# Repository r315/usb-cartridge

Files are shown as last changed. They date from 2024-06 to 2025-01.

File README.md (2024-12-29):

# GameBoy USB Cartridge

## Project Overview

Welcome to the GameBoy USB Cartridge project! This project aims to replicate a classic GameBoy cartridge and enhance it by adding a USB interface. This modification allows users to change the ROM content of the cartridge via a USB connection, making it a versatile and modern tool for GameBoy enthusiasts, developers, and collectors.

## Features

- **Classic GameBoy Cartridge Design**: Faithfully replicates the original cartridge's form factor and functionality.
- **USB Interface**: Enables easy ROM updates and data transfer through a USB connection.
- **Custom ROM Support**: Upload and play custom ROMs without the need for additional hardware.
- **Open Source**: Fully open-source hardware and software design, encouraging community contributions and modifications.

## Table of Contents

1. [Getting Started](#getting-started)
1. [Hardware Requirements](#hardware-requirements)
1. [Software Requirements](#software-requirements)
1. [Installation](#installation)
1. [Usage](#usage)
1. [Final notes](#final-notes)
1. [License](#license)

## Getting Started

GameBoy USB Cartridge is a diy project, so a custom pcb must be ordered and assembled.
I consider this project as dificult, since it requires the soldering of very fine pitch components
and requires good knowledge electronics and microcontroller wolkings in case of debug.

### Prerequisites

Ensure you have the following components and tools:

- GameBoy or GameBoy Color console
- Access to 3D printer for printing cartridge shell.
- Soldering tools and supplies
- Required hardware for Afterburrner gal programmer
- Jtag harware tool with SWD support

## Hardware Requirements

- **USB Cartridge pcb**: A bare pcb from your favorite pcb manufacturer (see hardware folder for schematic and gerber files)
- **Components**: Parts to populate pcb (see bom file on hardware folder)

## Software Requirements

- **Firmware Development**: Arm GNU Toolchain from arm Develop.
- **Afterburner pal programming**:  https://github.com/ole00/afterburner
- **Jtag software**: Can be Jlink or Openocd

## Installation

### Hardware Assembly

- Follow available schematic and assembly files.
- **Apply correction**: PCB has an error, in which the address line A0 is not connected to the correct pin of nor flash memory.
The workaround is connect a thin wire between pin 45 (Q15/A-1) to micro controller pin 36 (PF7).
- **Print 3D Case**: check cad files under hardware/case folder

<a href="/hardware/correction.jpg" target="_blank">
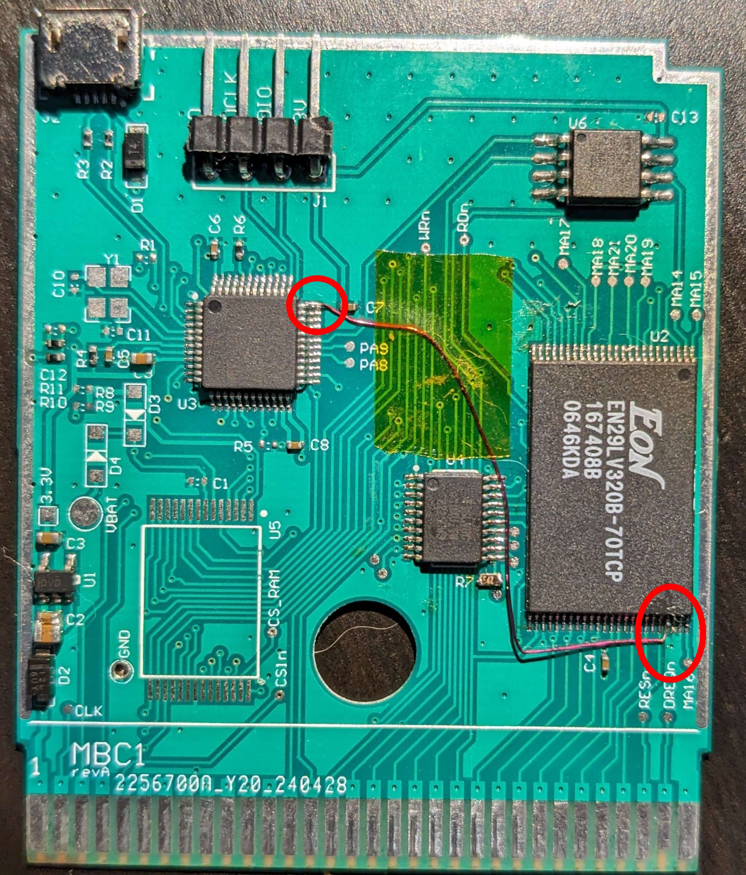
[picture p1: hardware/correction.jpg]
GameBoy USB Cartridge
    
</a>

### Firmware Upload

#### Programming pal

A JED file is provided for programming the pal, for his step I have used a modified version of Afterburner for Arduino with custom
hardware on a breadboard, but recommend using an Arduino with Afterburner.

The pal source file is also avaialble *mbc1.pld* and can be compiled with Wincupl, it is possible to compile a version that supports ram
but is limits the rom size and it has not been tested.

#### Programming microcontroller

To build microcontroller firmare, install Toolchain (I have used gcc version 10.3.1) and run *make* command.
If build is successful, *usb-cartridge.elf* will be available on *build* folder, use your jtag tool to program microcontroller.

## Usage

If all goes well with hardware and firmware, connecting USB Cartridge to a pc a serial device should be detected.
Also an unformated usb drive should be detected, format it as FAT.

Copy a rom file to that drive, the maximum rom size is 256kB, open a serial terminal and run commands:

1. `mount 1` this command mounts volume inside microcontroller.
1. `list`     list available files.
1. `rom program <romname>` programs given rom file into flash.

There are several other commands, typing *help* list all avaialble commands, typing some commands without parameters prints help of that command.
Code can be also checked for more command information.

Filally insert the cartrige and enjoy!

## Final notes

As mentioned this is a dificult project that requires good knowledge in electronics, since there is a lot of information that is 
omitted or not documented. One example is the flash memory support, I have used devices that were available to me and written drivers 
for them, it is very unlikely that the same parts will be available to other persons.
Firmware was written having that assumption in mind and flash driver is implemented in a way that should be easy to add new flash devices
or port it to other microcontroller.

If a new HW revision is drawn that fixes the error on address lines, firmware should also be udated in order to remove implemented workaround.

On mechanical side the 3D model for the case does not have an opening for USB connector, FreeCad project is available to be modified or a simple x-acto knife can be used to cut the opening.

## License

This project is licensed under the MIT License - see the [LICENSE](LICENSE) file for details.

---

Thank you for your interest in the GameBoy USB Cartridge project! We hope you enjoy building and using this modern take on a classic gaming accessory. If you have any questions or need assistance, please feel free to open an issue in the repository.

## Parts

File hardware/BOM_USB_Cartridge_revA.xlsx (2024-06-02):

Quantity | Designator | Comment | Description | Footprint | Value
1 | U2 | EN29LV320B-70TCP | FLASH - NOR Memory IC 64Mb (8M x 8) Parallel 70ns 48-TSOP | TSOP-48 | 64Mbit
1 | U3 | AT31F415CBT7 | Microcontroller - 32bit cortex-m4 | LQFP48_M
1 | U4 | ATF16V8C | EEPLD | TSSOP-20
1 | U6 | MX25L1635 | serial flash memory | SOP 8L (200mil) | 16Mbit
2 | R2, R3 | 0R | Resistor | R0402_HA | 0R
2 | D1, D2 | Diode | Generic Diode | SOD123 | 1N5711
3 | C2, C3, C9 | 1uF | Ceramic Capacitor, Ceramic Capacitor, Polarized Capacitor (Surface Mount) | C0603_HA | 1uF
6 | R1, R4, R5, R6, R10, R11 | 10k | Resistor | R0402_HA | 10k
1 | C4 | 10uF | Ceramic Capacitor | C0402_HA | 10uF
5 | C5, C6, C7, C8, C13 | 100nF | Ceramic Capacitor, Capacitor, Capacitor, Capacitor, Ceramic Capacitor | C0402_HA | 100nF
1 | J2 | CMU065803001 | MICRO USB 5P FEMALE DIP B -TYPE | CMU065803001 | CMU065803001
1 | U1 | RT9193-33 or Compatible | 300mA, Ultra-Low Noise, Ultra-Fast CMOS LDO Regulator | SOT23-5 | RT9193

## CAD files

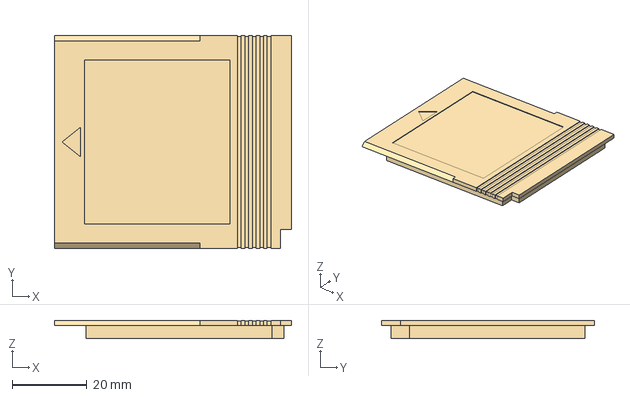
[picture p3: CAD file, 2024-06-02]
hardware/case/Cartridge-Lid.step
63.5 x 57.0 x 4.90 mm

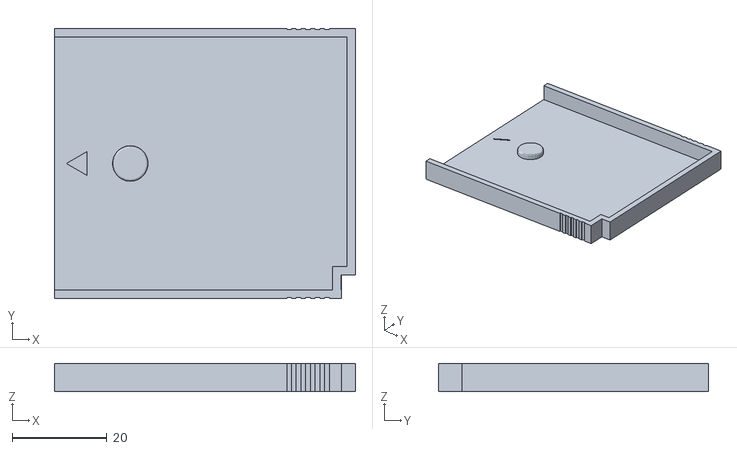
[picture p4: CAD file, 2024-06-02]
hardware/case/Cartridge-Base.stl
63.5 x 57.0 x 6.00

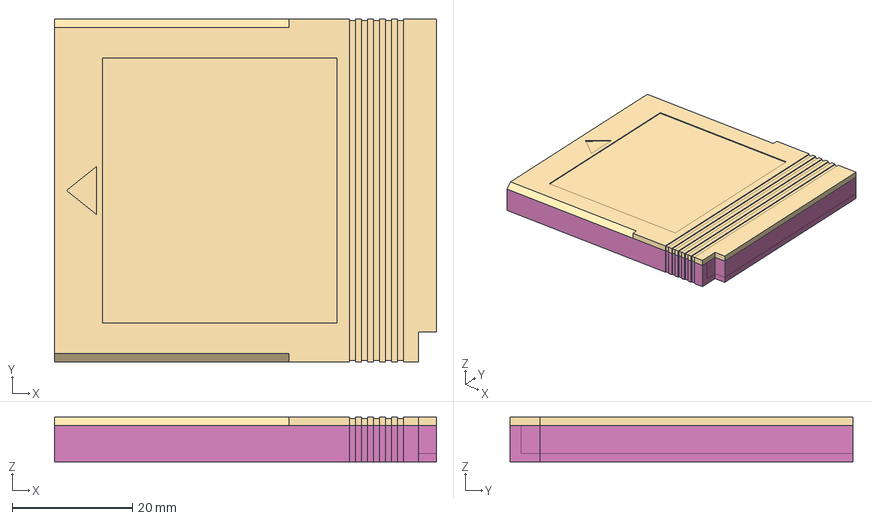
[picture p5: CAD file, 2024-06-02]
hardware/case/Cartridge.FCStd
63.5 x 57.0 x 7.40 mm
Base
Lid

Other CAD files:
hardware/case/Cartridge-Lid.stl

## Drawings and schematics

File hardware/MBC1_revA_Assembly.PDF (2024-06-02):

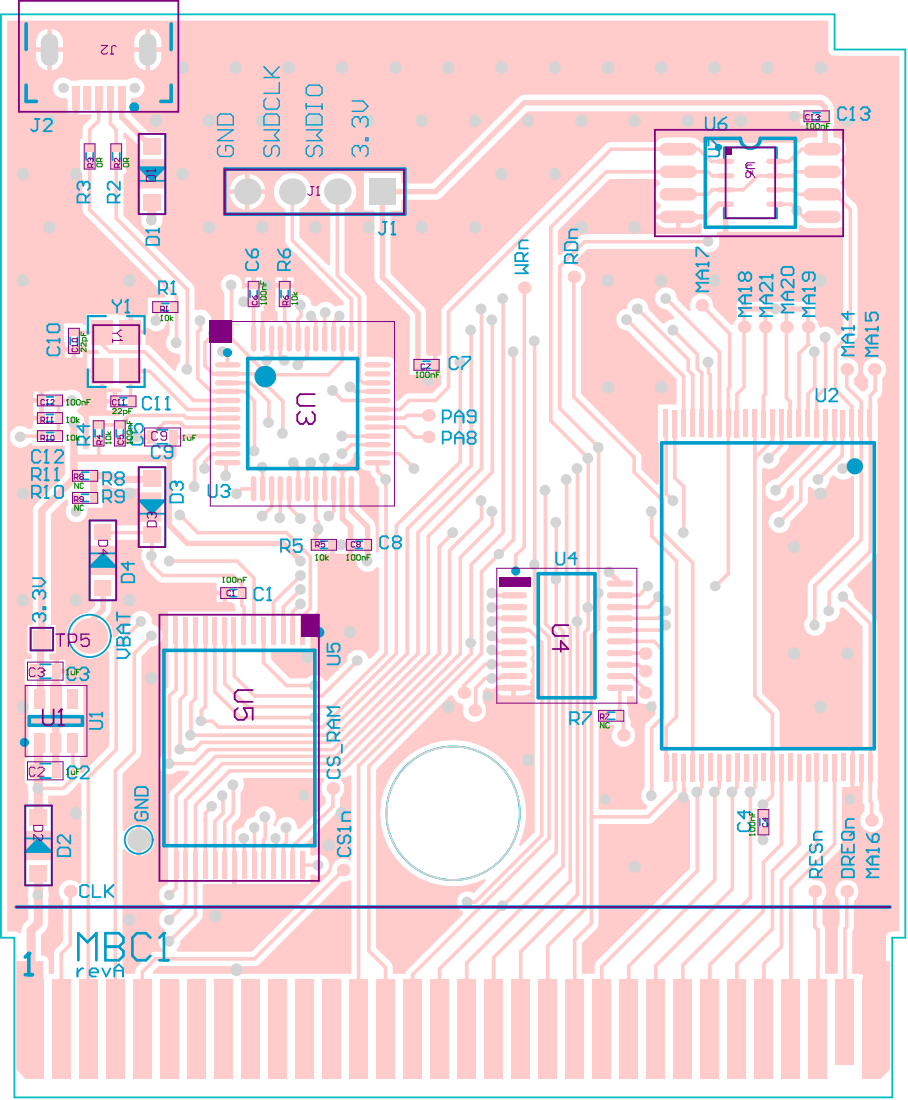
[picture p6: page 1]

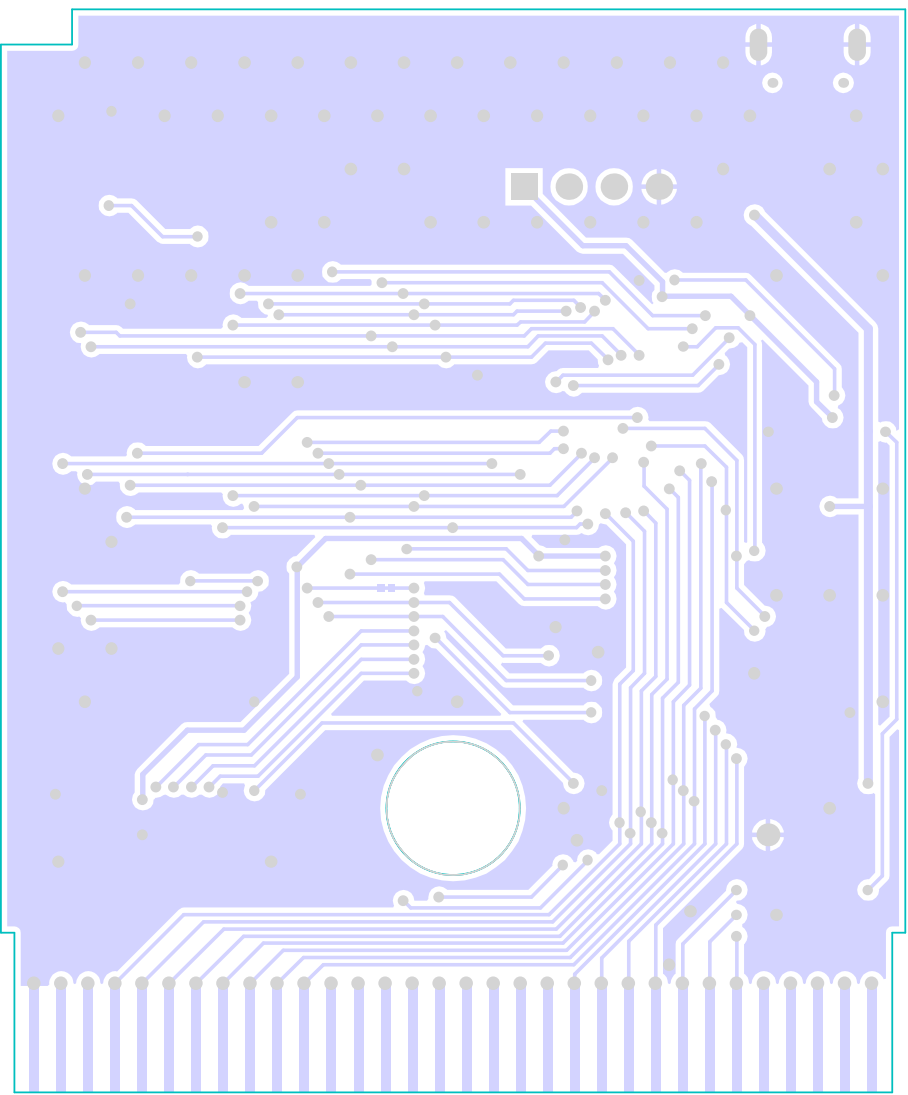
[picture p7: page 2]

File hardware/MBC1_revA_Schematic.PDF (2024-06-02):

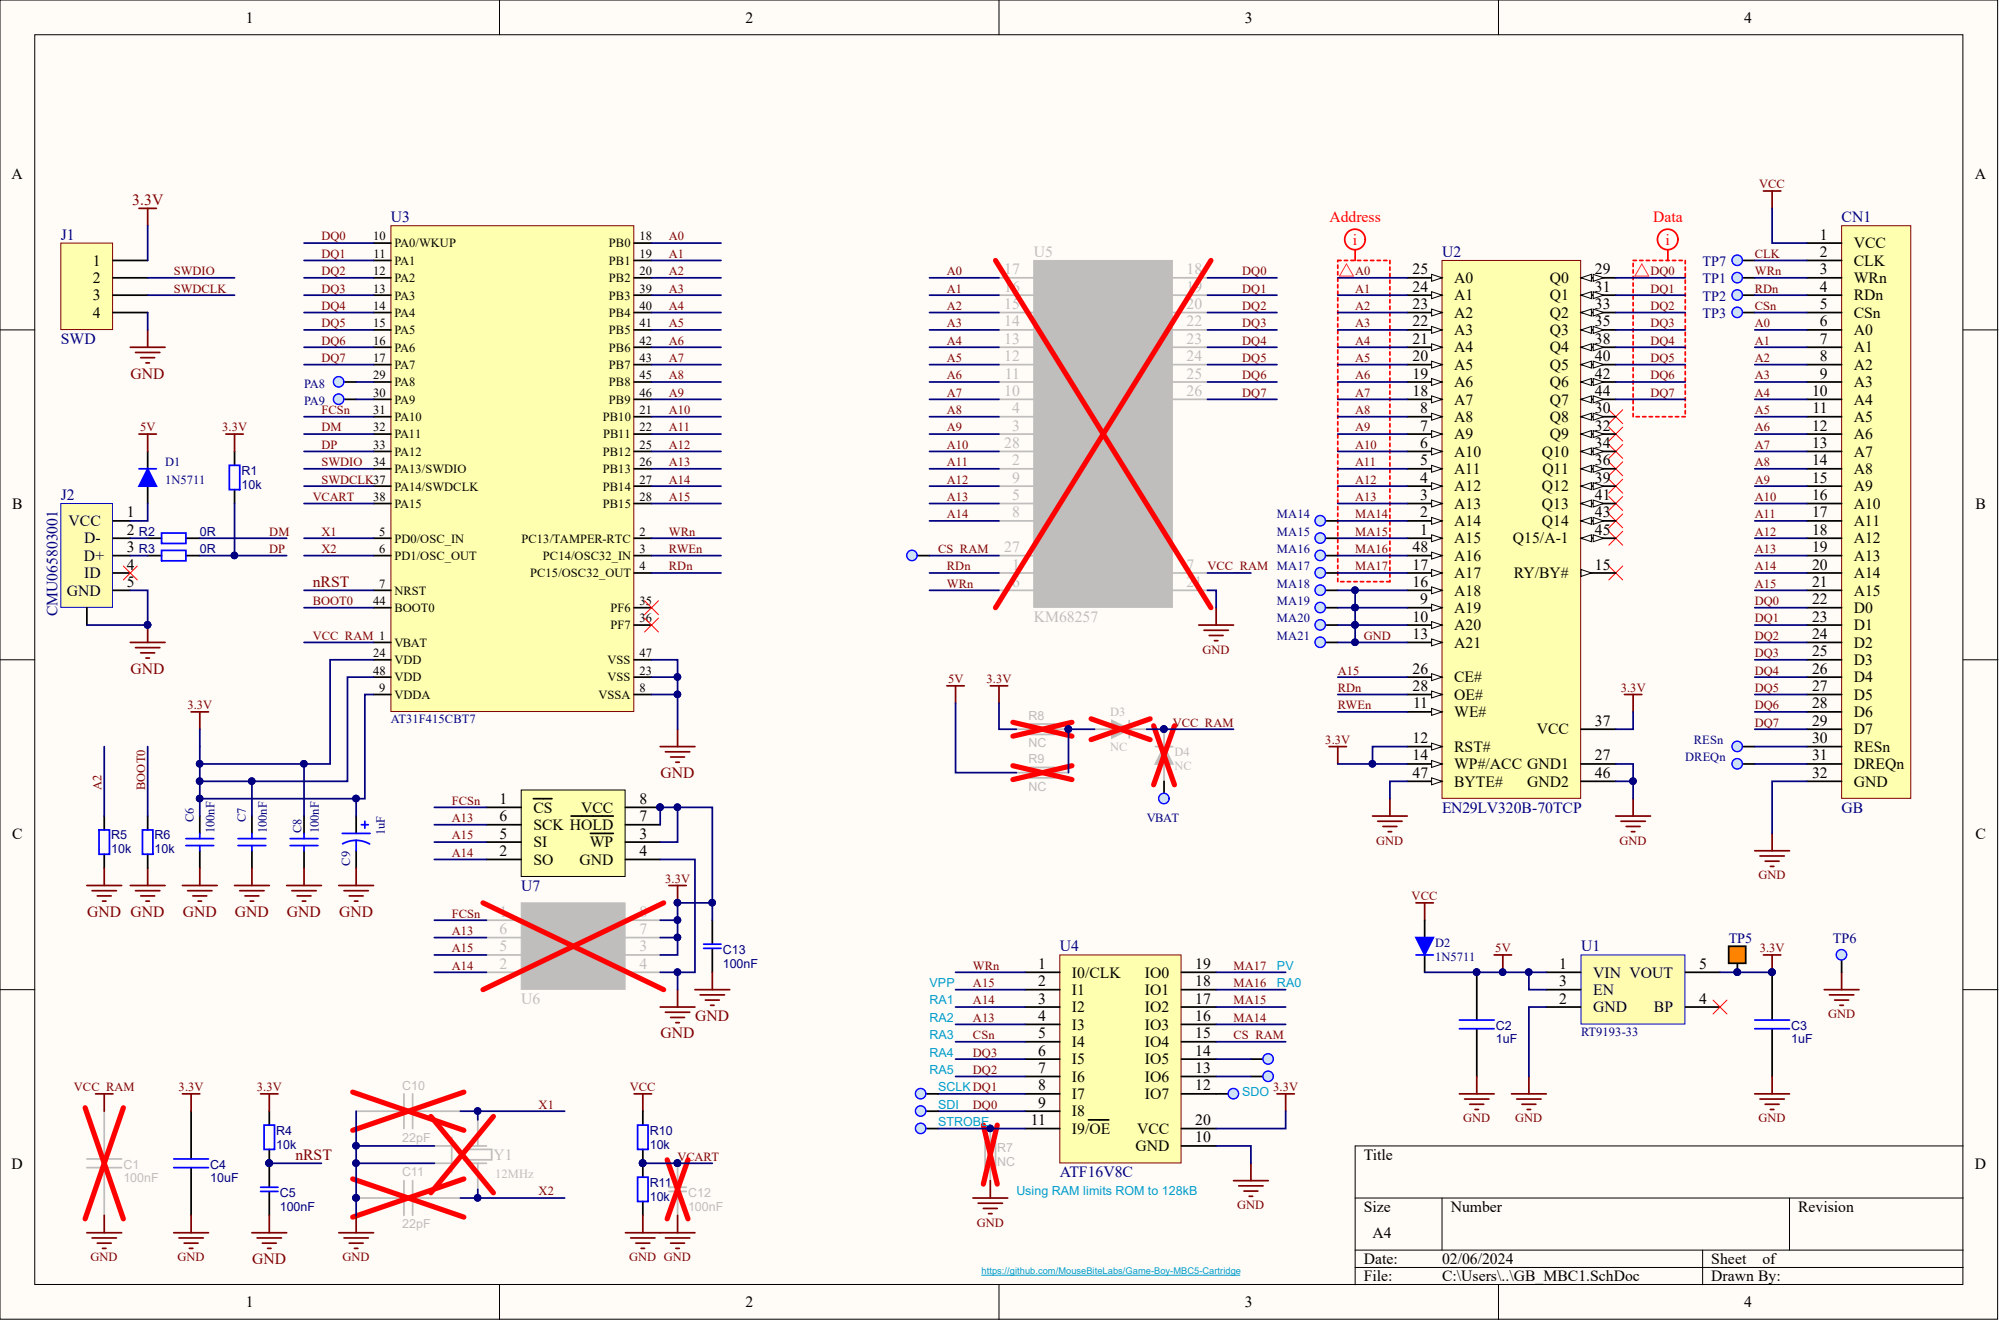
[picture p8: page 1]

A7 | A7 18 | DQ7
A8 | A8 8

Using RAM limits ROM to 128kB

https://github.com/MouseBiteLabs/Game-Boy-MBC5-Cartridge

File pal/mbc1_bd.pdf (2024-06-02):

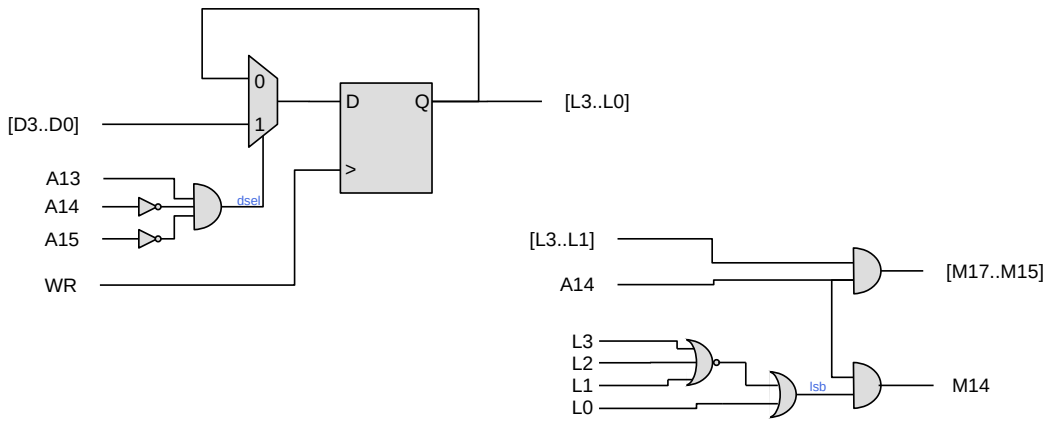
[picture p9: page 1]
dsel; lsb

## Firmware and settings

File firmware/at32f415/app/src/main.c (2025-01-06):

/**
  **************************************************************************
  * @file     main.c
  * @version  v2.0.8
  * @date     2022-04-25
  * @brief    main program
  **************************************************************************
  *                       Copyright notice & Disclaimer
  *
  * The software Board Support Package (BSP) that is made available to
  * download from Artery official website is the copyrighted work of Artery.
  * Artery authorizes customers to use, copy, and distribute the BSP
  * software and its related documentation for the purpose of design and
  * development in conjunction with Artery microcontrollers. Use of the
  * software is governed by this copyright notice and the following disclaimer.
  *
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
  **************************************************************************
  */

#include <stdlib.h>
#include <stdio.h>
#include <string.h>
#include "board.h"
#include "cli_simple.h"
#include "ff.h"
#include "msc_diskio.h"
#include "flashspi.h"
#include "flashnor.h"
#include "at32_norflash.h"
#include "at32_spiflash.h"

#define GAME_HEADER_SIZE    0x50
#define GAME_HEADER_ADDR    0x100
#define PROG_BLOCK_SIZE     1024
#define VERSION             "1.1.0"

typedef struct disksize_s{
	uint32_t totalsize;
	uint32_t freesize;
}disksize_t;

static FATFS fatfs;
const flash_t *pfls;
static uint8_t mounted;

static void printBuf(const uint8_t *buf, uint32_t len){
    for(int i = 0; i < len; i ++){
        if( (i & 15) == 0)
            printf("\n%02X: ", i & 0xF0);
        printf("%02X ", buf[i]);
    }
    putchar('\n');
}

static void printGameTitle(const uint8_t* title)
{
    for(uint8_t i = 0; i < 16; i++, title++){
        if(*title == '\0')
            break;
        putchar(*title);
    }

    putchar('\n');
}

static void printGameHeader(const uint8_t* header)
{
    // Dump logo
    printf("\nLogo:\n");
    printBuf(header + 4, 0x30);
    printGameTitle(header + 0x34);
    printf("Color:%s\n", (header[0x43] & 0x80) ? "Yes" : "No");
    printf("License: %02X%02X\n", header[0x44], header[0x45]);
    printf("GB/SGB: %02X\n", header[0x46]);
    printf("Cartridge type: %02X\n", header[0x47]);
    printf("Rom size: %02X\n", header[0x48]);
    printf("Ram size: %02X\n", header[0x49]);
    printf("Jp: %02X\n", header[0x4A]);
    printf("License (old): %02X\n", header[0x4B]);
    printf("Mask rom version: %02X\n", header[0x4C]);
    printf("Complement check: %02X\n", header[0x4D]);
    printf("Checksum: %02X%02X\n", header[0x4F], header[0x4E]);
}

FRESULT getDiskSize(TCHAR *path, disksize_t *disk_size)
{
	FATFS *pfs;
    FRESULT res;
	DWORD fre_clust;

	res = f_getfree(path, &fre_clust, &pfs);

	if(res == FR_OK){
		disk_size->totalsize = (pfs->n_fatent - 2) * pfs->csize / 2;
		disk_size->freesize = fre_clust * pfs->csize / 2;
	}

	return res;
}

FRESULT mount(TCHAR *path, uint8_t m)
{
    FRESULT r;
    disksize_t disk_size = {0};

    if(m)
    {
        if(mounted){
            printf("FS already mounted\n");
            return FR_OK;
        }

        r = f_mount(&fatfs, path, 0);  // 0 = mount later option

        printf("Mount ");
        if(r != FR_OK){
            printf("fail: %d\n", r);
        }else{
            r = getDiskSize(path, &disk_size);
            if(r == FR_OK){
                printf("ok\n"
                       "\tDisk size: %luk\n", disk_size.totalsize);
                printf("\t     Free: %luk\n", disk_size.freesize);
            }else{
                printf("FRESULT Error: %d\n", r);
            }
            mounted = 1;
        }
    }else{
        r = f_mount(NULL, "0:", 0);

        mounted = 0;

        printf("Unmounted\n");
    }

    return r;
}

static int readBlockFromFile(uint8_t *data, uint16_t len, const char *filename, uint32_t offset)
{
    FIL fil;
    FRESULT fr;
    UINT br = 0;

    if(!mounted){
        printf("No fs mounted\n");
        return -FR_NO_FILESYSTEM;
    }

    fr = f_open(&fil, filename, FA_READ);

    if(fr){
        printf("Error open: %d\n", fr);
        return -(int)fr;
    }

    fr = f_lseek(&fil, offset);

    if(fr){
        printf("Error seeking: %d", fr);
        goto err;
    }

    fr = f_read(&fil, data, len, &br);

    if(fr){
        printf("Error reading: %d", fr);
    }

err:
    f_close(&fil);

    return br;
}

static void selectFlashSPI(void){
    spiflash_init();
    pfls = flashspi_get();
}

static void selectFlashNOR(void){
    flashnor_init();
    pfls = flashnor_get();
}

static void rom_program_execute(const char* filename, uint8_t banking)
{
    uint8_t *block;
    uint32_t addr = 0;
    uint32_t progress = 0;
    int res, i = 0;

    block = (uint8_t*)malloc(PROG_BLOCK_SIZE);

    if(!block){
        printf("Fail allocation\n");
        return;
    }

    mem_bus_configure(MEM_BUS_SPI);

    if(!mounted)
        mount("0:", 1);

    if(readBlockFromFile(block, PROG_BLOCK_SIZE, filename, 0) <= 0){
        free(block);
        return;
    }

    selectFlashNOR();

    if(!pfls){
        printf("\nNo nor flash detected\n");
        free(block);
        return;
    }

    printf("\nErasing..\n");
    printf("%s\n", (pfls->erase(FLASH_CHIP_ERASE) == FLASH_OK) ? "ok" : "fail");

    if(banking)
        printGameHeader(block + GAME_HEADER_ADDR);

    while(1){
        if(res > 0){
            mem_bus_configure(MEM_BUS_NOR);

            if(banking){
                res = rom_program(pfls, block, addr, PROG_BLOCK_SIZE);
            }else{
                res = pfls->write(block, addr, PROG_BLOCK_SIZE);
            }

            if(res != FLASH_OK){
                printf("\nProgram failed at block: %lx\n", addr);
                break;
            }

            for(i = 0; i < PROG_BLOCK_SIZE; i++){
                uint8_t writen;

                if(banking){
                    writen = rom_byte_read(pfls, addr + i);
                }else{
                    writen = norflash_byte_read(addr + i);
                }

                if(writen != block[i]){
                    printf("\nFailed at address: %lx\n", addr + i);
                    i = PROG_BLOCK_SIZE;
                }
            }

            if(i == PROG_BLOCK_SIZE + 1){
                break;
            }

            addr += PROG_BLOCK_SIZE;

            if((progress & 0x1f) == 0){
                if(progress){
                    printf(" %lukB\n", progress);
                }else{
                    putchar('\n');
                }
            }

            putchar('#');
            progress++;

        }else{
            printf(" %lukB\nDone\n", progress);
            break;
        }

        mem_bus_configure(MEM_BUS_SPI);
        res = readBlockFromFile(block, PROG_BLOCK_SIZE, filename, addr);
    }

    free(block);
}

static int listCmd(int argc, char **argv)
{
    FRESULT res;
    FILINFO fileInfo;
    uint32_t totalFiles = 0;
    uint32_t totalDirs = 0;
    DIR dir;

    res = f_opendir(&dir, "/");

    if(res != FR_OK) {
        printf("f_opendir() failed, res = %d\r\n", res);
        return CLI_OK;
    }

    printf("--------\r\nRoot directory:\r\n");

    for(;;) {
        res = f_readdir(&dir, &fileInfo);
        if((res != FR_OK) || (fileInfo.fname[0] == '\0')) {
            break;
        }

        if(fileInfo.fattrib & AM_DIR) {
            printf("  DIR  %s\r\n", fileInfo.fname);
            totalDirs++;
        } else {
            printf("  FILE %s\r\n", fileInfo.fname);
            totalFiles++;
        }
    }

    printf("(total: %lu dirs, %lu files)\r\n--------\r\n", totalDirs, totalFiles);

    res = f_closedir(&dir);

    return CLI_OK;
}

static int mountCmd(int argc, char **argv)
{
    if(argc < 2){
        printf("usage: mount <0|1>\n");
        return CLI_BAD_PARAM;
    }

	mount("0:", argv[1][0] == '1');
    return CLI_OK;
}

static int resetCmd(int argc, char **argv)
{
    sw_reset();
    return CLI_OK;
}

static int versionCmd(int argc, char **argv)
{
    printf("%s\n", VERSION);
    return CLI_OK;
}

static int flashCmd(int argc, char **argv)
{
    flash_res_t res;

    if(argc < 2){
        printf("usage: flash <select|init|info|erase|read>\n");
        printf("\tinit\n");
        printf("\tinfo\n");
        printf("\terase [sector}\n");
        printf("\tformat, applies only to spi flash\n");
        printf("\tread <addr> <len>\n");
        printf("\tselect <nor|spi>\n");
        return CLI_OK_LF;
    }

    if(!strcmp(argv[1], "select")){
        if(!strcmp(argv[2], "nor")){
            selectFlashNOR();
        }else{
           selectFlashSPI();
        }
        return CLI_OK;
    }

    if(!pfls){
        printf("Flash not detected\n");
        return CLI_OK;
    }

    if(!strcmp(argv[1], "init")){
        pfls->init();
        return CLI_OK;
    }

    if(!strcmp(argv[1], "info")){
        printf("Name: %s\n", pfls->name);
        printf("Total size: %u (0x%08X) bytes\n", (unsigned int)pfls->size, (unsigned int)pfls->size);
        printf("Sector size: %u (0x%04X) bytes\n",  (unsigned int)pfls->sectorsize,  (unsigned int)pfls->sectorsize);
        printf("Page size: %u (0x%02X) bytes\n",  (unsigned int)pfls->pagesize,  (unsigned int)pfls->pagesize);

        if(pfls->opt & FLASH_OPT_CFI){
            uint8_t size = flashnor_cfi_read((uint8_t*)argv[0]); // FIX, don't use argv buffer
            printf("CFI bytes:\n");
            printBuf((const uint8_t*)argv[0], size);
        }
        return CLI_OK;
    }

    if(!strcmp(argv[1], "read")) {
        uint32_t addr;
        int32_t len;
        CLI_Ha2i(argv[2], &addr);
        CLI_Ia2i(argv[3], &len);
        if(addr < pfls->size && len < 512){
            uint8_t *buf = (uint8_t*)malloc(len);
            if(buf){
                pfls->read((uint8_t*)buf, addr, len);
                printBuf((const uint8_t*)buf, len);
                free(buf);
                return CLI_OK_LF;
            }
        }
    }

    if(!strcmp(argv[1], "write")) {
        pfls->write((const uint8_t*)"This is test data", 0 , 18);
        return CLI_OK_LF;
    }

    if(!strcmp(argv[1], "erase")) {
        int32_t sector;

        if(argc == 2){
            res = pfls->erase(FLASH_CHIP_ERASE);
        }else{
            CLI_Ia2i(argv[2], &sector);
            res = pfls->erase(sector);
        }

        if(res != FLASH_OK){
            printf("Error %d\n", res);
        }

        return CLI_OK;
    }

#if FF_USE_MKFS
    if(!strcmp(argv[1], "format")) {
        if((pfls->opt & FLASH_OPT_ITF_MASK) == FLASH_OPT_ITF_SPI){
            printf("Formating spi flash... ");
            res = f_mkfs("0:", NULL, fatfs.win, sizeof(fatfs.win));
            printf("%d\n", res);
            return CLI_OK;
        }
    }
#endif

    return CLI_BAD_PARAM;
}

static int romCmd(int argc, char **argv)
{
    if(argc < 2){
        printf("usage: rom <init|info|erase|program|bank|read>\n");
        printf("\tinfo [file],     prints game header stored on nor flash or from file\n");
        printf("\terase,           Erase NOR flash, same as 'flash erase' command\n");
        printf("\tread <addr> <n>, read n data from rom using cartride bus\n");
        printf("\treadb <addr>,    read byte from rom using cartride bus\n");
        printf("\tprogram <file>,  programs binary file into rom\n");
        return CLI_OK_LF;
    }

    if(!pfls){
        selectFlashNOR();
    }

    if(!strcmp(argv[1], "info")){
        uint8_t rom_header[GAME_HEADER_SIZE];
        if(argc == 2){
            selectFlashNOR();
            rom_read(pfls, rom_header, GAME_HEADER_ADDR, sizeof(rom_header));
        }else{
            selectFlashSPI();
            if(!mounted){
                if(mount("0:", 1) != FR_OK){
                    return CLI_ERROR;
                }
            }
            readBlockFromFile(rom_header, sizeof(rom_header) , argv[2], GAME_HEADER_ADDR);
        }
        printGameHeader(rom_header);
        return CLI_OK_LF;
    }

    if(!strcmp(argv[1], "erase")) {
        selectFlashNOR();
        if(pfls->erase(FLASH_CHIP_ERASE) != FLASH_OK){
            printf("Chip erase failed\n");
        }
        return CLI_OK;
    }

    if(!strcmp(argv[1], "program")) {

        if(argv[3]){
            if(!strcmp(argv[3], "no_bank")) {
                rom_program_execute(argv[2], 0);
                return CLI_OK;
            }
        }

        rom_program_execute(argv[2], 1);

        return CLI_OK;
    }

    /**
     * @brief Set rom bank
     * MA17:14 only change
     * on rom adresses above 0x4000
     */
    if(!strcmp(argv[1], "bank")) {
        uint32_t bank;
        CLI_Ia2i(argv[2], (int32_t*)&bank);

        if(bank < 32)
            rom_setBank(bank);

        return CLI_OK;
    }

    if(!strcmp(argv[1], "read")){
        uint32_t addr;
        uint32_t len;

        CLI_Ha2i(argv[2], &addr);
        CLI_Ia2i(argv[3], (int32_t*)&len);

        if(addr < pfls->size && len < 512){
            uint8_t *buf = (uint8_t*)malloc(len);
            if(buf){
                rom_read(pfls, (uint8_t*)buf, addr, len);
                printBuf((const uint8_t*)buf, len);
                free(buf);
                return CLI_OK_LF;
            }
        }
    }

    if(!strcmp(argv[1], "readb")){
        uint32_t addr;

        CLI_Ha2i(argv[2], &addr);
        if(addr < pfls->size){
            uint8_t data = rom_byte_read(pfls, addr);
            printf("%02X\n", data);
            return CLI_OK;
        }
    }

    return CLI_BAD_PARAM;
}

cli_command_t cli_cmds [] = {
    {"help", ((int (*)(int, char**))CLI_Commands)},
    {"reset", resetCmd},
    {"rom", romCmd},
    {"mount", mountCmd},
    {"list", listCmd},
    {"flash", flashCmd},
    {"ver", versionCmd}
};

/**
  * @brief  main function.
  * @param  none
  * @retval none
  */
int main(void)
{
    uint8_t inserted;

    board_init();

    CLI_Init("cart >");
    CLI_RegisterCommand(cli_cmds, sizeof(cli_cmds) / sizeof(cli_command_t));
#ifdef MBC1_REVA
    insertDetection_init();
#else
    selectFlashNOR();
    mem_bus_configure(MEM_BUS_SPI);
#endif
    mounted = 0;

    delay_ms(500);  // some delay before checking if is inserted

    inserted = isInserted();

    if(!inserted){
        connectUSB();
    }

	while(1){
        if(inserted){
            if(isInserted()){
                LED1_OFF;
                delay_ms(100);
            }else{
                connectUSB();
                inserted = 0;
            }
        }else{
            if(isInserted()){
                disconnectUSB();
                inserted = 1;
            }else{
                if(usb_isConnected()){
                    if(CLI_ReadLine()){
                        CLI_HandleLine();
                    }
                    LED1_ON;
                    delay_ms(20);
                }
            }
	    }
    }
}

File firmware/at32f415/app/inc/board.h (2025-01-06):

#ifndef _board_h_
#define _board_h_

#include "at32_norflash.h"
#include "at32_spiflash.h"
#include "at32f415.h"

#define LED1_OFF        GPIOA->scr = (1 << 8)
#define LED1_ON         GPIOA->clr = (1 << 8)
#define LED1_TOGGLE     GPIOA->odt = GPIOA->idt ^ (1 << 8)
#define LED1_INIT \
        CRM->apb2en_bit.gpioaen = 1; \
        GPIOA->cfghr |= (6 << 0)

enum mem_bus {
    MEM_BUS_NONE = 0,
    MEM_BUS_SPI,
    MEM_BUS_NOR,
};

void board_init(void);
void system_clock_config(void);
void system_tick_init(void);
void cycle_count_init(void);
void delay_init(void);
void delay_ms(uint32_t ms);
void delay_us(uint32_t us);
uint32_t get_tick(void);
void usb_clock48m_select(usb_clk48_s clk_s);
void usb_config(void);
void usb_unplug(void);
uint8_t usb_isConnected(void);
void disconnectUSB(void);
void connectUSB(void);
void sw_reset(void);
uint32_t serial_read(uint8_t *data, uint32_t len);
uint32_t serial_write(const uint8_t *buf, uint32_t len);
uint32_t serial_available(void);
uint8_t isInserted(void);
void insertDetection_init(void);
flash_res_t rom_read(const flash_t *flash, uint8_t *data, uint32_t address, uint32_t len);
void rom_setBank(uint8_t bank);
uint8_t rom_byte_read(const flash_t *flash, uint32_t address);
flash_res_t rom_program(const flash_t *flash, const uint8_t *data, uint32_t addr, uint32_t len);
void mem_bus_configure(uint8_t bus);
#endif

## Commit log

2024-12-29 Updated cli-simple (bug fixes) and code format
    [gb_mbc1_board.c, main.c]
2024-12-31 Added mbm29f040 flash driver
2025-01-05 MOV: Functions to upper level Replace fixed assignments by macros
    [at32_norflash.c, at32_norflash.h, board.h]
2025-01-06 FIX: Wrong data port
    [at32_norflash.c, at32_norflash.h]
2025-01-06 FIX: write rom bank
    [gb_mbc1_board.c]
2025-01-06 FIX: Rom program failure
    [gb_mbc1_board.c]
2025-01-06 ADD: renessas flash spi support
